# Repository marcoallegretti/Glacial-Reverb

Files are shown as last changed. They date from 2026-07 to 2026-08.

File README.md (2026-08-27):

# Koloured-Verb

A 12 HP Eurorack stereo reverb built on a Daisy Patch SM, using the
[eurorack-blocks](https://github.com/ohmtech-rdi/eurorack-blocks) framework.
Three boards: a carrier for the Daisy, a control board, and the panel.

Twelve reverb voices grouped into six families, ten post-reverb tail effects
grouped into five families, and a freeze pad with ducking.

## Rooms

Selected with the **ROOM** button. Short press cycles the family (RGB colour),
long press cycles the variant within it (RGB brightness dips = variant number).

| Family  | Colour  | Variants |
|---|---|---|
| Hall | blue | FDN tank · chamber |
| Plate | green | Dattorro · vintage · dispersive |
| Spring  | cyan | classic · long tank · dispersive  |
| Shimmer | yellow  | octave up · octave down (Abyss) |
| Cloud | magenta | granular over an FDN tank |
| Ambient | red | modulated Hadamard FDN |

Three variants per family is the ceiling: the LED renders a variant as a shade
of the family colour, and a fourth step is not readable against off.

The chamber runs a Moorer early-reflection tap bank and feeds the tank from the
taps rather than from the input, so each tap seeds the tank and the density
builds without the reflections reading as discrete echoes. The vintage plate
holds its high-frequency decay near a second whatever the decay knob does, as a
steel plate does. The long tank spreads its three spring delays while keeping
their chirp cutoffs together — the inverse of the short tank — and scatters at
the mid-point coupling ring. The dispersive voices use stretched-allpass chains
for the chirp.

## Tail effects

Selected with the **FX** button, same gesture (short = family, long = variant).
The red LED blinks the family number; None leaves the LED off. Each effect is
added over the untouched tail, so amount 0 is a true bypass.

| Family | Variants |
|---|---|
| None | — |
| Pitch | octave up · sub · chord (5th)  |
| Modulate | chorus · formant |
| Texture  | granular · reverse |
| Resonant | resonator · droplet |

## Panel

| Control | Function |
|---|---|
| FX pot | Morph: model character and tail-effect depth together |
| DECAY | Tail length |
| MIX | Wet added over the dry (additive, not a crossfade) |
| PRE DL | Pre-delay |
| DUCK | Input ducks the reverb |
| FRZ LV | Frozen pad level |
| FRZ MX | How much new signal enters the frozen pad |
| FRZ btn | Short press = freeze on/off · long press = tank-only on/off |
| ROOM btn  | Short = room family · long = variant |
| FX btn | Short = effect family · long = variant |
| FRZ G | Gate: forces freeze on |
| FX / FRZ LV / MIX / DECAY | CV over the corresponding pot |
| IN L/R | Audio in (R normalled to L) |
| OUT L/R | Audio out |

CV drives continuous character; the buttons handle discrete structure. Room and
effect selection step discretely rather than sweeping: a switch renders both
voices through a 150 ms crossfade and clears the outgoing one only once it is
silent, so the tail carries across a switch.

## Layout

```
eurorack/
  KoloredVerb.erbui          panel and control definition
  KoloredVerb.{h,cpp}        UI glue: selectors, gestures, LEDs
  KoloredVerbDsp.{h,cpp}     freeze pad, duck, mix, pre-delay wrapper
  dsp/                       reverb models, tail effects, shared DSP

hardware/
  core-board/                carrier: Daisy Patch SM, power, I/O expansion
  control-board/             pots, jacks, buttons, LEDs
  panel-board/               12 HP front panel
```

Each board folder holds its KiCad sources and a `fab/` directory with the
gerber zip and loose gerber set. See [hardware/README.md](hardware/README.md)
for the stack and what mates to what.

## Building

See [BUILD.md](BUILD.md) for the toolchain, firmware, simulator and board
fabrication. The `eurorack-blocks` framework is not vendored in this repository.

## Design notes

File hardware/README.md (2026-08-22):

# Koloured-Verb — hardware

Three boards, one 12 HP module.

```
  panel-board      12 HP FR4 panel: cutouts and baked labels
       │  pots / jacks / LEDs poke through
  control-board    panel parts on F.Cu, carrier headers on B.Cu
       │  ZZ1-5 / ZZ7 / ZZ12 + J6 / J9 / J11 plug down into…
  core-board       Daisy Patch SM host, power, I/O expansion
       │  4× 5×2 sockets host…
  Daisy Patch SM   Electrosmith submodule (bought, not fabricated)
```

| Folder | Board | Size | Assembly |
|---|---|---|---|
| [`core-board/`](core-board/) | carrier | 59.75 × 109.65 mm | 45 SMD by JLCPCB, 12 through-hole by hand |
| [`control-board/`](control-board/) | pots, jacks, buttons, LEDs | 59.75 × 109.65 mm | all by hand; one SMD RGB LED |
| [`panel-board/`](panel-board/) | 12 HP panel | 60.75 × 128.65 mm | none |

All three are 2-layer, 1.6 mm FR4. Each folder holds its KiCad sources, a
`<board>.bom.csv`, and `fab/` with the gerber zip and the loose set it was built
from. The core board also carries `fab/*-jlcpcb-bom.csv` and `-cpl.csv` for
assembly.

`ZZ10` on the control board is **DNP** — the core board carries no microSD, so
that header has no mating socket.

## Gerbers

```sh
kicad-cli pcb export gerbers --no-protel-ext \
  --layers F.Cu,B.Cu,F.Mask,B.Mask,F.Paste,B.Paste,F.Silkscreen,B.Silkscreen,Edge.Cuts \
  -o <board>/fab/gerber/ <board>/<name>.kicad_pcb
kicad-cli pcb export drill -o <board>/fab/gerber/ <board>/<name>.kicad_pcb
```

then zipped from `fab/gerber/`. The panel yields no paste layers — it carries no
SMD pads.

## Regenerating

The panel comes from `eurorack/KoloredVerb.erbui`; its labels are baked vector
outlines and cannot be edited in KiCad:

```sh
python3 hardware/panel-board/regen_panel.py
```

The control board cannot be regenerated — `erbb build hardware` parses it with a
KiCad-6-era reader that throws on KiCad 10 net syntax. Edit it in KiCad and treat
the committed board as the source of truth.

The core board's assembly files are derived from its own PCB:

```sh
"…/KiCad/10.0/bin/python.exe" hardware/core-board/derive_assembly.py
```

## Licensing

The control board and panel are generated from eurorack-blocks blocks, and the
core board derives from its kivu12. All carry **CC BY-SA 4.0** by derivation.
See [THIRD-PARTY.md](../THIRD-PARTY.md).

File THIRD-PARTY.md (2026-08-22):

# Third-party code and licences

KoloredVerb is not standalone work. What follows is what it stands on, who owns
it, and what that obliges us to do. Each entry was traced to a file in this
repository or in `deps/`, not assumed.

## Vendored into this repository

### `eurorack/dsp/ReverbSc.{h,cpp}` — MIT, © 2017 Raphael Dinge

Copied from `eurorack-blocks`, `samples/dsp/ReverbSc.{h,cpp}`. Verified identical
by its delay table (`{ 2473, 44, 14226, 1966 }`, upstream line 190).

This file is load-bearing: Hall wraps it, Shimmer and Abyss wrap it, Cloud runs
granular over it, and the freeze pad *is* it. Twelve of twelve rooms depend on it.

It is vendored rather than referenced so the DSP compiles standalone — against a
heap-backed `erb::SdramPtr` stub for the offline harness, and directly into the
MetaModule plugin, which has no eurorack-blocks at all.

The algorithm is Sean Costello's `reverbsc` (Stautner–Puckette FDN) as it appears
in Csound; the implementation here is Raphael Dinge's.

> **The copyright line above was missing.** Both files carried only
> `ReverbSc.cpp (local copy)` until it was restored. MIT's single obligation is
> that the notice travels with the copy, so that omission was a licence
> violation for as long as it stood. It is recorded here rather than quietly
> fixed.

## Built against, not vendored

### eurorack-blocks — MIT (software) / CC BY-SA 4.0 (hardware)

Per its README: *"All files in this repository, excluding `submodules/`, are
provided with the CC BY-SA 4.0 license for the hardware part, and MIT license for
the software part"*, with exceptions listed there (fonts under SIL OFL, etc.).

Both halves reach this project, and they are not the same licence:

- **Software (MIT)** — `erb::SdramPtr`, the `.erbui` code generators, the block
  library, the VCV Rack and Daisy build targets.
- **Hardware (CC BY-SA 4.0)** — the control board and panel are generated from
  eurorack-blocks blocks and the kivu12 board. **ShareAlike is copyleft**: the
  boards in `hardware/` carry BY-SA obligations regardless of
  the licence chosen for the software.

### kivu12 carrier board — part of eurorack-blocks (CC BY-SA 4.0, hardware)

**`hardware/core-board/` is an adaptation of the eurorack-blocks kivu12 rev7**,
by Raphael Dinge, used under CC BY-SA 4.0 and shared under the same licence.

Modified: parts this module does not use were removed (the second CD4051 and
CD4021 with their front ends, the CV-pitch conditioning block, the microSD block
and eleven LED resistors), CI1/CI2 were hard-wired to the ADC in place of the
jumpers, two freed Daisy inputs were tied to GND, and the eurorack-blocks logo
was removed from the silkscreen. The remaining routing is the original author's.

`hardware/core-board/reference-kivu12/` holds JLCPCB ordering files *derived*
from the framework's own fab set — rows removed, no values edited.

### Daisy Patch SM / libDaisy — Electrosmith

Reached as an eurorack-blocks submodule. `submodules/` are excluded from the
eurorack-blocks licence and carry their own.

## Status

- [x] ReverbSc copyright restored (`.cpp` and `.h`)
- [x] `LICENSE` — EUPL 1.2 for this project's own work
- [ ] MetaModule SDK terms — tracked on the `metamodule-port` branch, which is
      not part of this (master) history and must be settled before that branch
      is published. `metamodule/plugin.json` there still says
      `"license": "proprietary"`, a placeholder.

## On choosing a licence for our own work

MIT and CC BY-SA 4.0 upstream leave the software side open: MIT is permissive, so
MIT code may be carried into a copyleft work provided its notice travels with it —
which is what the restored header and this file are for.

The hardware is the constraint, not the software. CC BY-SA 4.0 attaches to the
boards by derivation, and a software licence does not displace it. Whatever is
chosen for the code, the boards stay ShareAlike.

This is a record of what the files say, not legal advice.

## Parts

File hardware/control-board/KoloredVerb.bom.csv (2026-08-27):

References | Description | MPN | Remarks | Quantity | Distributor | Distributor Part Number | Distributor Part URL
ZZ1 | CONN HEADER VERT 12POS 2.54MM | PBC12SAAN |  | 1 | Digikey | S1011E-12-ND | https://www.digikey.de/en/products/detail/sullins-connector-solutions/PBC12SAAN/859633
ZZ3, ZZ4, ZZ7, ZZ12 | CONN HEADER VERT 8POS 2.54MM | PBC08SAAN |  | 4 | Digikey | S1011E-08-ND | https://www.digikey.de/en/products/detail/sullins-connector-solutions/PBC08SAAN/859629
J11, J9 | CONN HEADER VERT 2POS 2.54MM | PBC02SAAN |  | 2 | Digikey | S1011E-02-ND | https://www.digikey.de/en/products/detail/sullins-connector-solutions/PBC02SAAN/859623
J6 | CONN HEADER VERT 4POS 2.54MM | PBC04SAAN |  | 1 | Digikey | S1011E-04-ND | https://www.digikey.de/en/products/detail/sullins-connector-solutions/PBC04SAAN/859625
ZZ10 | CONN HEADER VERT 6POS 2.54MM | PBC06SAAN | DNP - the core board has no microSD, so this header has no mating socket. Fitting it leaves 6 pins in the gap above the core board. | 0 | Digikey | S1011E-06-ND | https://www.digikey.de/en/products/detail/sullins-connector-solutions/PBC06SAAN/859627
ZZ2 | CONN HEADER VERT 9POS 2.54MM | PBC09SAAN |  | 1 | Digikey | S1011E-09-ND | https://www.digikey.de/en/products/detail/sullins-connector-solutions/PBC09SAAN/859630
ZZ5 | CONN HEADER VERT 10POS 2.54MM | PBC10SAAN |  | 1 | Digikey | PBC10SAAN | https://www.digikey.de/en/products/detail/sullins-connector-solutions/PBC10SAAN/859631
RV1, RV2, RV3, RV4, RV5, RV6, RV7 | ALPHA 9MM POTS – VERTICAL D-SHAFT | RD901F-40-15R1-B100K |  | 7 | Thonk | RD901F-B100K | https://www.thonk.co.uk/shop/alpha-9mm-pots-dshaft/
H3, H4, H5, H6, H7, H8, H9 | 1PS - Small Pointer (D Shaft) - Rogan PT Plastic Knob | Rogan 1PS |  | 7 | Thonk |  | https://www.thonk.co.uk/shop/make-noise-mutable-style-knobs/
J1, J10, J12, J2, J3, J4, J5, J7, J8 | Thonkiconn – 3.5mm Jack Sockets | PJ398SM |  | 9 | Thonk | PJ398SM | https://www.thonk.co.uk/shop/thonkiconn/
H10, H11, H12, H13, H14, H15, H16, H17, H18 | Knurled Nuts | PJ398SM nut | One nut bag contains already 50 pieces | 9 | Thonk |  | https://www.thonk.co.uk/shop/thonkiconn/
SW1, SW2, SW3 | C&K TACTILE SWITCH | D6R00 F1 LFS | Choose Black | 3 | Thonk |  | https://www.thonk.co.uk/shop/radio-music-switch/
D1, D3 | LED RED DIFFUSED T-1 T/H | WP710A10ID |  | 2 | Digikey | 754-1606-ND | https://www.digikey.com/en/products/detail/kingbright/WP710A10ID/2769809
D2 | LED RGB SMD PLCC4 - Cree CLV1A-FKB (common anode, FX indicator) | CLV1A-FKB-CJ1M1F1BB7R4S3 |  | 1 | Digikey | CLV1A-FKB-CJ1M1F1BB7R4S3 | https://www.cree.com/led-components/media/documents/CLV1AFKB(874).pdf

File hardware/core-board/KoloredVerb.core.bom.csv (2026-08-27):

References | Description | MPN | Quantity | Distributor | Distributor Part Number | LCSC Part Number
C1 C2 | CAP CER 10UF 25V X5R 0805 | CL21A106KAYNNNE | 2 | Digikey | 1276-2891-1-ND | C15850
C3 C5 C8 | CAP CER 0.1UF 25V X7R 0603 | CC0603KRX7R9BB104 | 3 | Digikey | 478-7018-1-ND | C14663
D1 D2 D3 D4 D5 D6 D7 D8 D30 | DIODE ARRAY SCHOTTKY 40V SOT323 | BAT54SW | 9 | Digikey | 497-14153-1-ND | C22466373
D23 D24 | DIODE SCHOTTKY 40V 1A SOD123 | B5819W SL | 2 | Digikey | 1N5819HW-FDICT-ND | C8598
Dummy1 Dummy2 Dummy3 Dummy4 | CONN HDR 10POS 0.1 GOLD PCB | PPPC052LFBN-RC | 4 | Digikey | S7108-ND
Dummy5 | CONN HEADER VERT 36POS 2.54MM | PBC36SAAN | 1 | Digikey | S1011E-36-ND
J0 | CONN HEADER VERT 10POS 2.54MM | 61201021621 | 1 | Digikey | 732-2094-ND
J1 | CONN HDR 12POS 0.1 TIN PCB | PPTC121LFBN-RC | 1 | Digikey | S6100-ND
J2 | CONN HDR 9POS 0.1 TIN PCB | PPTC091LFBN-RC | 1 | Digikey | S7007-ND
J3 J7 | CONN HDR 8POS 0.1 TIN PCB | PPTC081LFBN-RC | 2 | Digikey | S7006-ND
J4 | CONN HDR 8POS 0.1 TIN PCB | PPTC081LFBN-RC | 1 | Digikey | S7006-ND
J5 | CONN HDR 10POS 0.1 TIN PCB | PPTC101LFBN-RC | 1 | Digikey | S7008-ND
J6 | CONN HDR 4POS 0.1 TIN PCB | PPTC041LFBN-RC | 1 | Digikey | S7002-ND
J9 | CONN HDR 2POS 0.1 TIN PCB | PPTC021LFBN-RC | 1 | Digikey | S7000-ND
J11 | CONN HDR 2POS 0.1 TIN PCB | PPTC021LFBN-RC | 1 | Digikey | S7000-ND
J12 | CONN HDR 8POS 0.1 TIN PCB | PPTC081LFBN-RC | 1 | Digikey | S7006-ND
L1 L2 | FERRITE BEAD 1 KOHM 0603 1LN | BLM18AG102SN1D | 2 | Digikey | 732-1586-1-ND | C85824
R1 R47 R48 R49 R50 R51 | RES SMD 1K OHM 1% 1/10W 0603 | 0603WAF1001T5E | 6 | Digikey | 311-1KLDCT-ND | C21190
R4 R5 R6 R7 R8 R14 R15 R16 | RES SMD 100K OHM 1% 1/10W 0603 | 0603WAF1003T5E | 8 | Digikey | 541-100KHCT-ND | C25803
R79 R80 | RES SMD 4.7K OHM 1% 1/10W 0603 | 0603WAF4701T5E | 2 | Digikey | 311-4.70KHRCT-ND | C23162
R84 R85 R86 R87 R88 R89 R90 R91 | RES SMD 1M OHM 1% 1/10W 0603 | 0603WAF1004T5E | 8 | Digikey | 541-1.00MHCT-ND | C22935
U1 | IC MUX/DEMUX 8X1 16TSSOP | CD4051BPWR | 1 | Digikey | 296-11993-1-ND | C54587
U3 | IC STATIC SHFT REG 8STG 16-TSSOP | CD4021BPWR | 1 | Digikey | 296-14256-1-ND | C2877061
U6 | IC LED DRIVER RGBA 28-TSSOP | PCA9685PW | 1 | Digikey | 568-11925-1-ND | C2678753
DPSM1 | Audio submodule, plugs into the 4 sockets below | DAISY-PATCH-SM | 1 | Electrosmith | DAISY-PATCH-SM

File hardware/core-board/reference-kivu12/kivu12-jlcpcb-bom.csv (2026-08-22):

Comment | Designator | Footprint | LCSC Part #
100k | R4,R5,R6,R7,R8,R14,R15,R16,R17,R18,R24,R25,R26,R27,R28,R34,R68,R69,R72,R73,R81,R82 | Resistor_SMD:R_0603_1608Metric | C25803
1K | R1,R2,R44,R45,R46,R47,R48,R49,R50,R51,R52,R53,R54,R55,R56,R57,R58,R59 | Resistor_SMD:R_0603_1608Metric | C21190
1M | R84,R85,R86,R87,R88,R89,R90,R91,R92,R93,R94,R95,R96,R97,R98,R99 | Resistor_SMD:R_0603_1608Metric | C22935
4.7k | R79,R80 | Resistor_SMD:R_0603_1608Metric | C23162
4.99k | R76 | Resistor_SMD:R_0603_1608Metric | C23046
100n | C3,C4,C5,C6,C8,C11,C12 | Capacitor_SMD:C_0603_1608Metric | C14663
1u | C13 | Capacitor_SMD:C_0603_1608Metric | C15849
10u | C1,C2 | Capacitor_SMD:C_0805_2012Metric | C15850
BAT54SW | D1,D2,D3,D4,D5,D6,D7,D8,D9,D10,D11,D12,D13,D14,D15,D16,D30 | Package_TO_SOT_SMD:SOT-323_SC-70 | C22466373
D_Schottky | D23,D24 | Diode_SMD:D_SOD-123 | C8598
Ferrite_Bead | L1,L2 | Inductor_SMD:L_0603_1608Metric | C85824
4051 | U1,U2 | Package_SO:TSSOP-16_4.4x5mm_P0.65mm | C54587
4021 | U3,U4 | Package_SO:TSSOP-16_4.4x5mm_P0.65mm | C2877061
LM4040DBZ-5 | D22 | Package_TO_SOT_SMD:SOT-23 | C156291
PCA9685PW | U6 | Package_SO:TSSOP-28_4.4x9.7mm_P0.65mm | C2678753
TL072 | U9 | Package_SO:SOIC-8_3.9x4.9mm_P1.27mm | C67473

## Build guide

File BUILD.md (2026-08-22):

# Building and fabricating Koloured-Verb

## Toolchain

- [eurorack-blocks](https://github.com/ohmtech-rdi/eurorack-blocks) — not vendored
  here. Clone it and initialise its submodules (`gyp-next` is required to generate
  the build; `vcv-rack-sdk` for the simulator):

  ```sh
  git submodule update --init submodules/gyp-next submodules/vcv-rack-sdk
  ```

  Point the project at it via `dep/eurorack-blocks` (a link or junction).
- Python 3.12 (the framework's bundled `python3-packages` are built for cp312).
- MinGW-w64 g++ (MSYS2 `mingw64`) on Windows.
- KiCad 10 for the boards and `kicad-cli` gerber export. The framework's panel
  generators separately shell out to a **bundled KiCad 6**, which lives under
  `build-system/toolchain/` and is not part of the source tree.

### Local layout on this machine

The framework is kept in `deps/eurorack-blocks/` so builds do not reach into
whichever scattered clone happens to be on `PATH`. Three links make that work —
all inside gitignored `dep/`/`deps/`, so none of this is committed:

| Link | Target | Why |
|---|---|---|
| `dep/eurorack-blocks` | `deps/eurorack-blocks` | what the build system looks for |
| `deps/eurorack-blocks/submodules/gyp-next` | a populated clone | needed to *generate* the build |
| `deps/eurorack-blocks/submodules/vcv-rack-sdk` | a populated SDK | `libRack` for the simulator |
| `deps/eurorack-blocks/build-system/toolchain` | the bundled toolchain | KiCad 6 + cairo DLLs for the panel generators |

Invoke the **vendored** `erbb`, not whichever one is on `PATH`:

```sh
deps/eurorack-blocks/build-system/scripts/erbb
```

This matters: the generated `KoloredVerbUi.h` bakes in the path to
`BoardKivu12.h`, so an `erbb` from a different clone silently compiles the
firmware against that clone's framework instead of the vendored one.

## Firmware (Daisy)

```sh
erbb configure
erbb build daisy --configuration release
```

## Simulator (VCV Rack)

```sh
erbb configure
erbb build simulator --configuration debug
```

Headless on Windows, MSYS `make` drops the MinGW `PATH` when spawning `g++`, so
the compile step fails even though the source generation succeeded. Run make
directly from a shell that has the environment set:

```sh
export PATH="/c/msys64/mingw64/bin:$PATH"
export HOME=/c/Users/<you>; export MSYSTEM=MINGW64
cd eurorack/artifacts/simulator && make -j1 install
```

The plugin installs to `%LOCALAPPDATA%/Rack2/plugins-win-x64/KoloredVerb/`.
This target never touches the hardware files.

### The generated manifest carries the wrong identity

`erbui/generators/vcvrack/manifest.py` writes `plugin.json` with the framework's
identity hardcoded — slug `ErbPluginKoloredVerb`, brand and author `Erb`, every
URL pointing at ohmtech-rdi, and `"license": "proprietary"` — and it rewrites the
file on **every** build, so the correction cannot be committed into the artifact.
Stamp it afterwards:

```sh
python3 ci/vcv_manifest.py $(find eurorack/artifacts -name plugin.json)
```

That sets the 23DSP identity and the EUPL-1.2 licence, and leaves the module slug
alone — it has to keep matching the string `plugin_vcvrack.cpp` passes to
`rack::createModel`. The release workflow runs this step automatically and also
stamps the tag as the version.

## Hardware fabrication

Deliverables live under `hardware/`, one folder per board:

| Board | Gerbers | BOM |
|---|---|---|
| Core | `core-board/fab/KoloredVerb.core.gerber.zip` | `core-board/KoloredVerb.core.bom.csv` |
| Control | `control-board/fab/KoloredVerb.gerber.zip` | `control-board/KoloredVerb.bom.csv` |
| Panel | `panel-board/fab/KoloredVerb.panel.gerber.zip` | none — mechanical |

All 2-layer, 1.6 mm FR4; the panel is fabricated as a PCB like the boards.

The core board's 45 SMD parts are assembled by JLCPCB from
`core-board/fab/KoloredVerb.core-jlcpcb-bom.csv` and `-cpl.csv`; its 12
through-hole parts and the whole control board are hand-soldered. `ZZ10` on the
control board is DNP — the core board has no microSD, so it has no mating socket.

### Regenerating the panel

The panel is FR4 (`material pcb` in the `.erbui`), so it is fabricated from
gerbers like the other two boards — no DXF or PDF is emitted, and none is
needed. Labels are baked to vector outlines and cannot be edited in KiCad, so
any label or control change has to come back through the `.erbui`:

```sh
python3 hardware/panel-board/regen_panel.py
```

Use a Python **3.12** interpreter — the framework's bundled `python3-packages`
(cffi, cairo) are cp312 builds.

The script calls only the four `generate_front_panel_*` steps, then re-exports
the gerbers with `kicad-cli`. It deliberately does **not** call
`erbb build hardware`, which would run `generate_front_pcb_kicad_pcb` against
the frozen control board. As a backstop it sha256s the control board before and
after and fails loudly if it moved.

Regeneration is faithful but not byte-stable: KiCad footprint UUIDs and the
footprint ordering are regenerated each run, so the `.kicad_pcb` churns while
the board does not. Verify by exported geometry, not by file hash — after the
rename regeneration the vertex set of every gerber layer was unchanged.

### Control board: do not regenerate

`erbb build hardware` cannot regenerate `KoloredVerb.kicad_pcb`. The framework
reads the existing board with a KiCad 6 era parser, which throws on KiCad 10 net
syntax. Placement is owned by the `.erbui`, but apply control-board changes directly
in KiCad and keep the committed board as the source of truth. Only the panel
generators above are safe to re-run; hash the control board before and after any
build to confirm it is untouched.

## Verifying the DSP

The DSP is host-independent and can be exercised without hardware or Rack:
compile `KoloredVerbDsp.cpp` against a heap-backed `erb::SdramPtr` stub and
drive it with impulses and noise, measuring RT60, L/R correlation, peak, NaN and
stability across every model x effect combination.

Build with `-D_GLIBCXX_ASSERTIONS` so `std::array::operator[]` traps
out-of-range indices, and use the simulator's real sample rate (48014, not
48000). Delay-line index bugs can need seconds of runtime to surface, so soak
each combination rather than sampling it briefly.

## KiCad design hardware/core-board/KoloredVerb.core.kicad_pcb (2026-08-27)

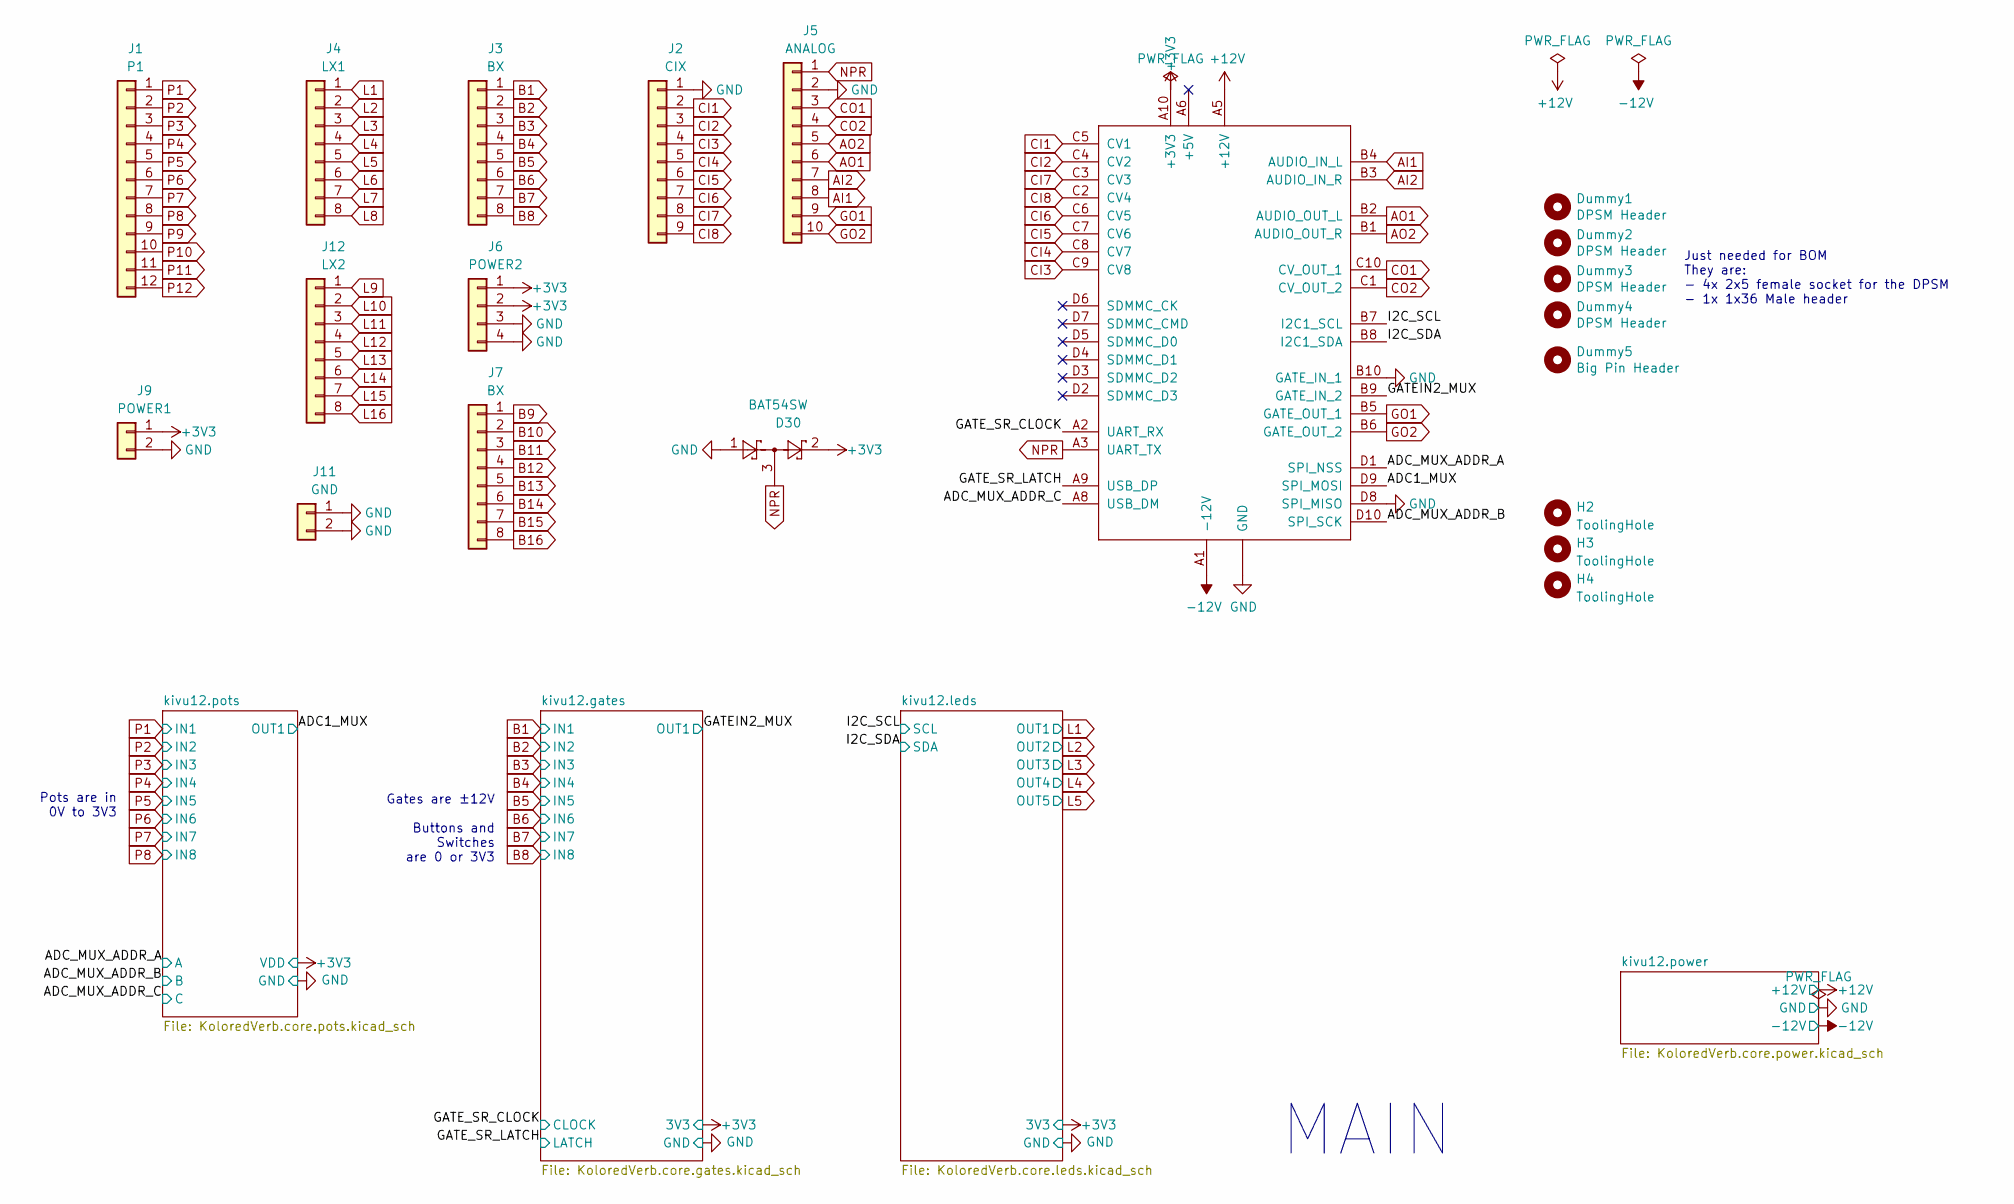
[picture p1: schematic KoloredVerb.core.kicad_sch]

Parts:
D30: BAT54SW; SOT-323_SC-70; MPN BAT54SW; JlcPcbPartNumber C22466373
DPSM1: DaisyPatchSm_Rev1; DaisyPatchSm; MPN DAISY-PATCH-SM
Dummy1, Dummy2, Dummy3, Dummy4: DPSM Header; Empty; MPN PPPC052LFBN-RC
Dummy5: Big Pin Header; Empty; MPN PBC36SAAN
H2, H3, H4: ToolingHole; JlcPcbToolingHole
J1: P1; PinSocket_1x12_P2.54mm_Vertical; MPN PPTC121LFBN-RC
J2: CIX; PinSocket_1x09_P2.54mm_Vertical; MPN PPTC091LFBN-RC
J3, J7: BX; PinSocket_1x08_P2.54mm_Vertical; MPN PPTC081LFBN-RC
J4: LX1; PinSocket_1x08_P2.54mm_Vertical; MPN PPTC081LFBN-RC
J5: ANALOG; PinSocket_1x10_P2.54mm_Vertical; MPN PPTC101LFBN-RC
J6: POWER2; PinSocket_1x04_P2.54mm_Vertical; MPN PPTC041LFBN-RC
J9: POWER1; PinSocket_1x02_P2.54mm_Vertical; MPN PPTC021LFBN-RC
J11: GND; PinSocket_1x02_P2.54mm_Vertical; MPN PPTC021LFBN-RC
J12: LX2; PinSocket_1x08_P2.54mm_Vertical; MPN PPTC081LFBN-RC

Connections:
+3V3: D30.2, DPSM1.A10 (+3V3), J6.1, J6.2, J9.1; also elsewhere on the board
+12V: DPSM1.A5 (+12V); also elsewhere on the board
-12V: DPSM1.A1 (-12V); also elsewhere on the board
/ADC1_MUX: DPSM1.D9 (SPI_MOSI); also elsewhere on the board
/ADC_MUX_ADDR_A: DPSM1.D1 (SPI_NSS); also elsewhere on the board
/ADC_MUX_ADDR_B: DPSM1.D10 (SPI_SCK); also elsewhere on the board
/ADC_MUX_ADDR_C: DPSM1.A8 (USB_DM); also elsewhere on the board
/GATEIN2_MUX: DPSM1.B9 (GATE_IN_2); also elsewhere on the board
/GATE_SR_CLOCK: DPSM1.A2 (UART_RX); also elsewhere on the board
/GATE_SR_LATCH: DPSM1.A9 (USB_DP); also elsewhere on the board
/I2C_SCL: DPSM1.B7 (I2C1_SCL); also elsewhere on the board
/I2C_SDA: DPSM1.B8 (I2C1_SDA); also elsewhere on the board
AI1: DPSM1.B4 (AUDIO_IN_L), J5.8
AI2: DPSM1.B3 (AUDIO_IN_R), J5.7
AO1: DPSM1.B2 (AUDIO_OUT_L), J5.6
AO2: DPSM1.B1 (AUDIO_OUT_R), J5.5
B1: J3.1; also elsewhere on the board
B2: J3.2; also elsewhere on the board
B3: J3.3; also elsewhere on the board
B4: J3.4; also elsewhere on the board
B5: J3.5; also elsewhere on the board
B6: J3.6; also elsewhere on the board
B7: J3.7; also elsewhere on the board
B8: J3.8; also elsewhere on the board
B9: J7.1
B10: J7.2
B11: J7.3
B12: J7.4
B13: J7.5
B14: J7.6
B15: J7.7
B16: J7.8
CI1: DPSM1.C5 (CV1), J2.2
CI2: DPSM1.C4 (CV2), J2.3
CI3: DPSM1.C9 (CV8), J2.4
CI4: DPSM1.C8 (CV7), J2.5
CI5: DPSM1.C7 (CV6), J2.6
CI6: DPSM1.C6 (CV5), J2.7
CI7: DPSM1.C3 (CV3), J2.8
CI8: DPSM1.C2 (CV4), J2.9
CO1: DPSM1.C10 (CV_OUT_1), J5.3
CO2: DPSM1.C1 (CV_OUT_2), J5.4
GND: D30.1, DPSM1.A4 (GND), DPSM1.A7 (GND), DPSM1.B10 (GATE_IN_1), DPSM1.D8 (SPI_MISO), J2.1, J5.2, J6.3, J6.4, J9.2, J11.1, J11.2; also elsewhere on the board
GO1: DPSM1.B5 (GATE_OUT_1), J5.9
GO2: DPSM1.B6 (GATE_OUT_2), J5.10
L1: J4.1; also elsewhere on the board
L2: J4.2; also elsewhere on the board
L3: J4.3; also elsewhere on the board
L4: J4.4; also elsewhere on the board
L5: J4.5; also elsewhere on the board
L6: J4.6
L7: J4.7
L8: J4.8
L9: J12.1
L10: J12.2
L11: J12.3
L12: J12.4
L13: J12.5
L14: J12.6
L15: J12.7
L16: J12.8
NPR: D30.3, DPSM1.A3 (UART_TX), J5.1
P1: J1.1; also elsewhere on the board
P2: J1.2; also elsewhere on the board
P3: J1.3; also elsewhere on the board
P4: J1.4; also elsewhere on the board
P5: J1.5; also elsewhere on the board
P6: J1.6; also elsewhere on the board
P7: J1.7; also elsewhere on the board
P8: J1.8; also elsewhere on the board
P9: J1.9
P10: J1.10
P11: J1.11
P12: J1.12

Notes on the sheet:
Just needed for BOM They are: - 4x 2x5 female socket for the DPSM - 1x 1x36 Male header
Pots are in 0V to 3V3
Gates are ±12V Buttons and Switches are 0 or 3V3
MAIN

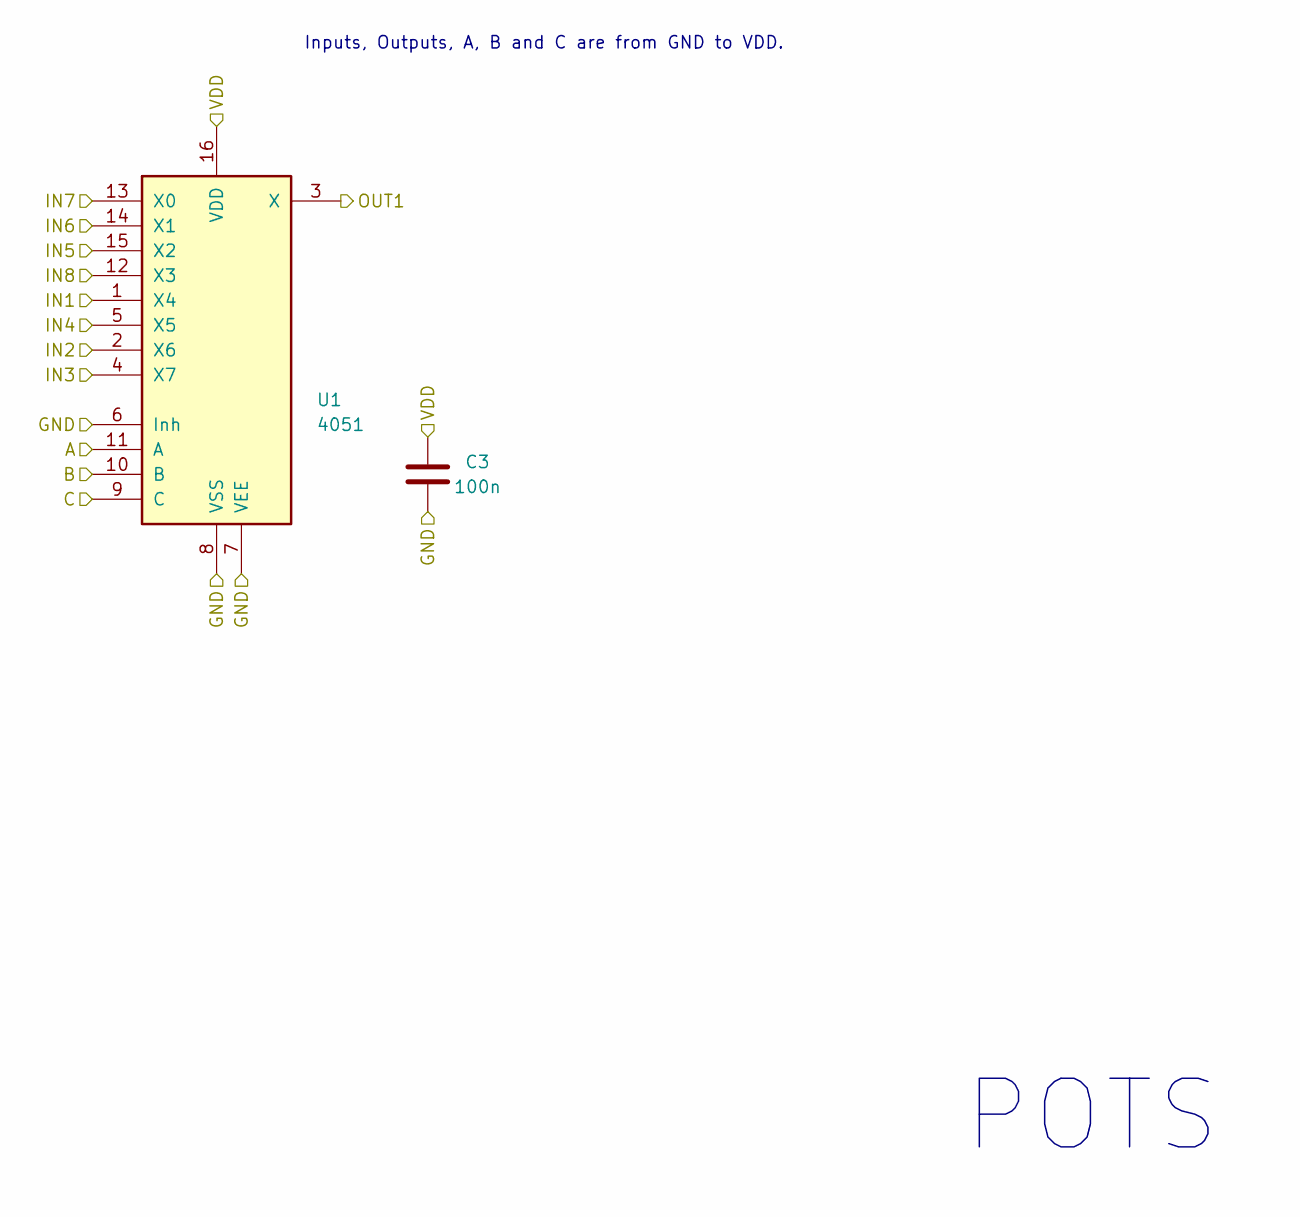
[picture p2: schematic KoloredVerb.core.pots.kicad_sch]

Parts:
C3: 100n; C_0603_1608Metric; MPN CC0603KRX7R9BB104; JlcPcbPartNumber C14663
U1: 4051; TSSOP-16_4.4x5mm_P0.65mm; MPN CD4051BPWR; JlcPcbPartNumber C54587

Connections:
+3V3: C3.2, U1.16 (VDD); also elsewhere on the board
/ADC1_MUX: U1.3 (X); also elsewhere on the board
/ADC_MUX_ADDR_A: U1.11 (A); also elsewhere on the board
/ADC_MUX_ADDR_B: U1.10 (B); also elsewhere on the board
/ADC_MUX_ADDR_C: U1.9 (C); also elsewhere on the board
GND: C3.1, U1.6 (Inh), U1.7 (VEE), U1.8 (VSS); also elsewhere on the board
P1: U1.1 (X4); also elsewhere on the board
P2: U1.2 (X6); also elsewhere on the board
P3: U1.4 (X7); also elsewhere on the board
P4: U1.5 (X5); also elsewhere on the board
P5: U1.15 (X2); also elsewhere on the board
P6: U1.14 (X1); also elsewhere on the board
P7: U1.13 (X0); also elsewhere on the board
P8: U1.12 (X3); also elsewhere on the board

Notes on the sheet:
Inputs, Outputs, A, B and C are from GND to VDD.
POTS

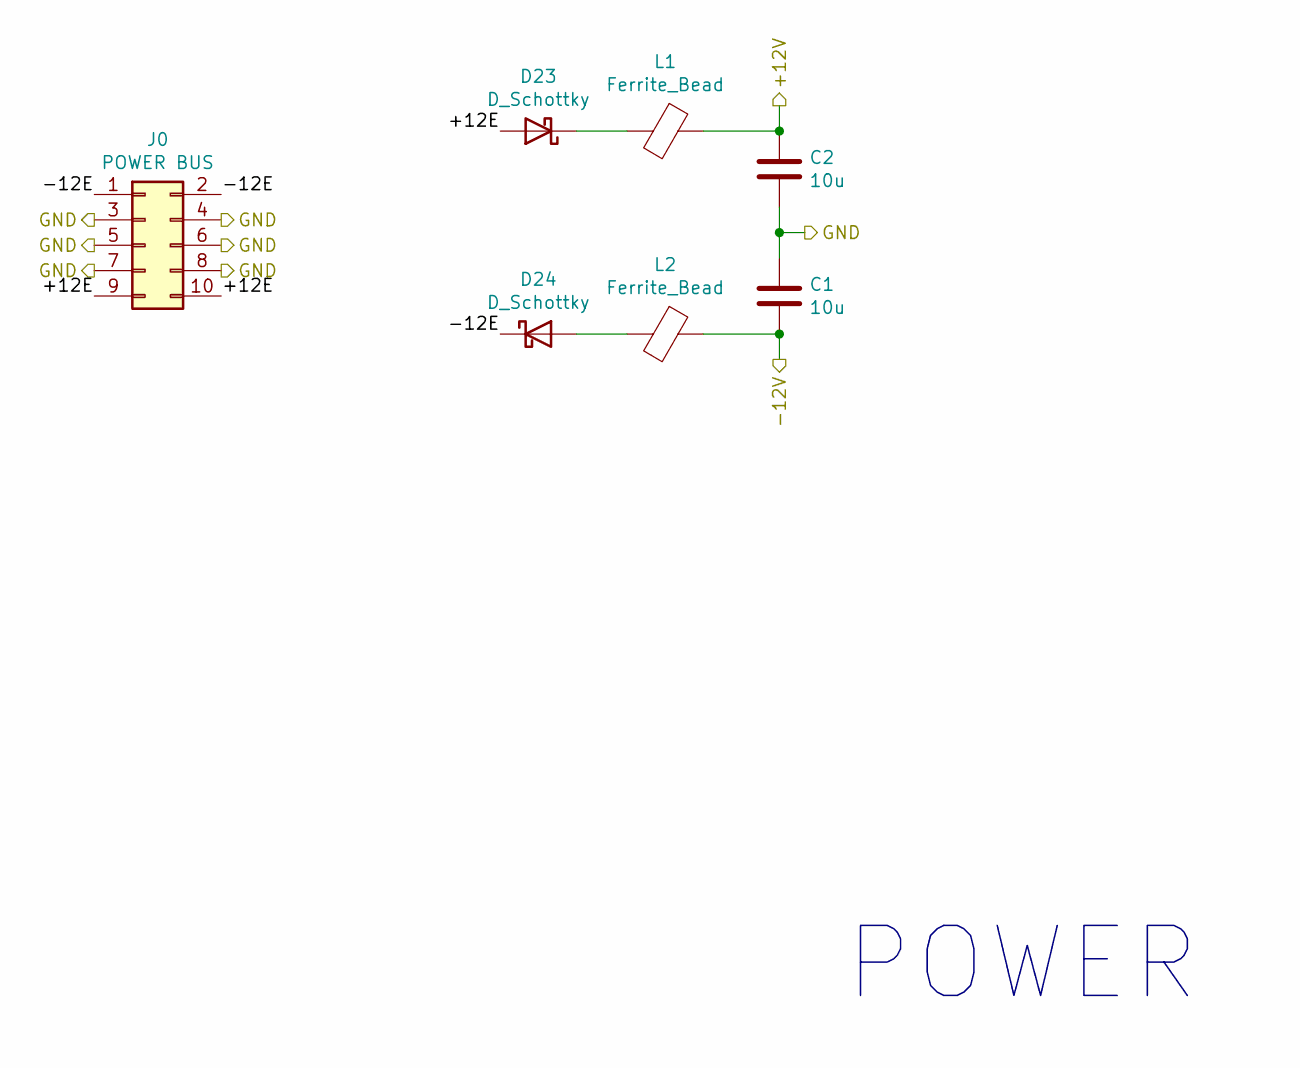
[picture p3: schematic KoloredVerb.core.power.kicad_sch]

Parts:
C1, C2: 10u; C_0805_2012Metric; MPN CL21A106KAYNNNE; JlcPcbPartNumber C15850
D23, D24: D_Schottky; D_SOD-123; MPN B5819W SL; JlcPcbPartNumber C8598
J0: POWER BUS; IDC-Header_2x05_P2.54mm_Vertical; MPN 61201021621
L1, L2: Ferrite_Bead; L_0603_1608Metric; MPN BLM18AG102SN1D; JlcPcbPartNumber C85824

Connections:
+12V: C2.1, L1.1; also elsewhere on the board
-12V: C1.2, L2.1; also elsewhere on the board
/kivu12.power/+12E: D23.2 (A), J0.9, J0.10
/kivu12.power/-12E: D24.1 (K), J0.1, J0.2
GND: C1.1, C2.2, J0.3, J0.4, J0.5, J0.6, J0.7, J0.8; also elsewhere on the board
unnamed: D23.1 (K), L1.2
unnamed: D24.2 (A), L2.2

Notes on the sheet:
POWER

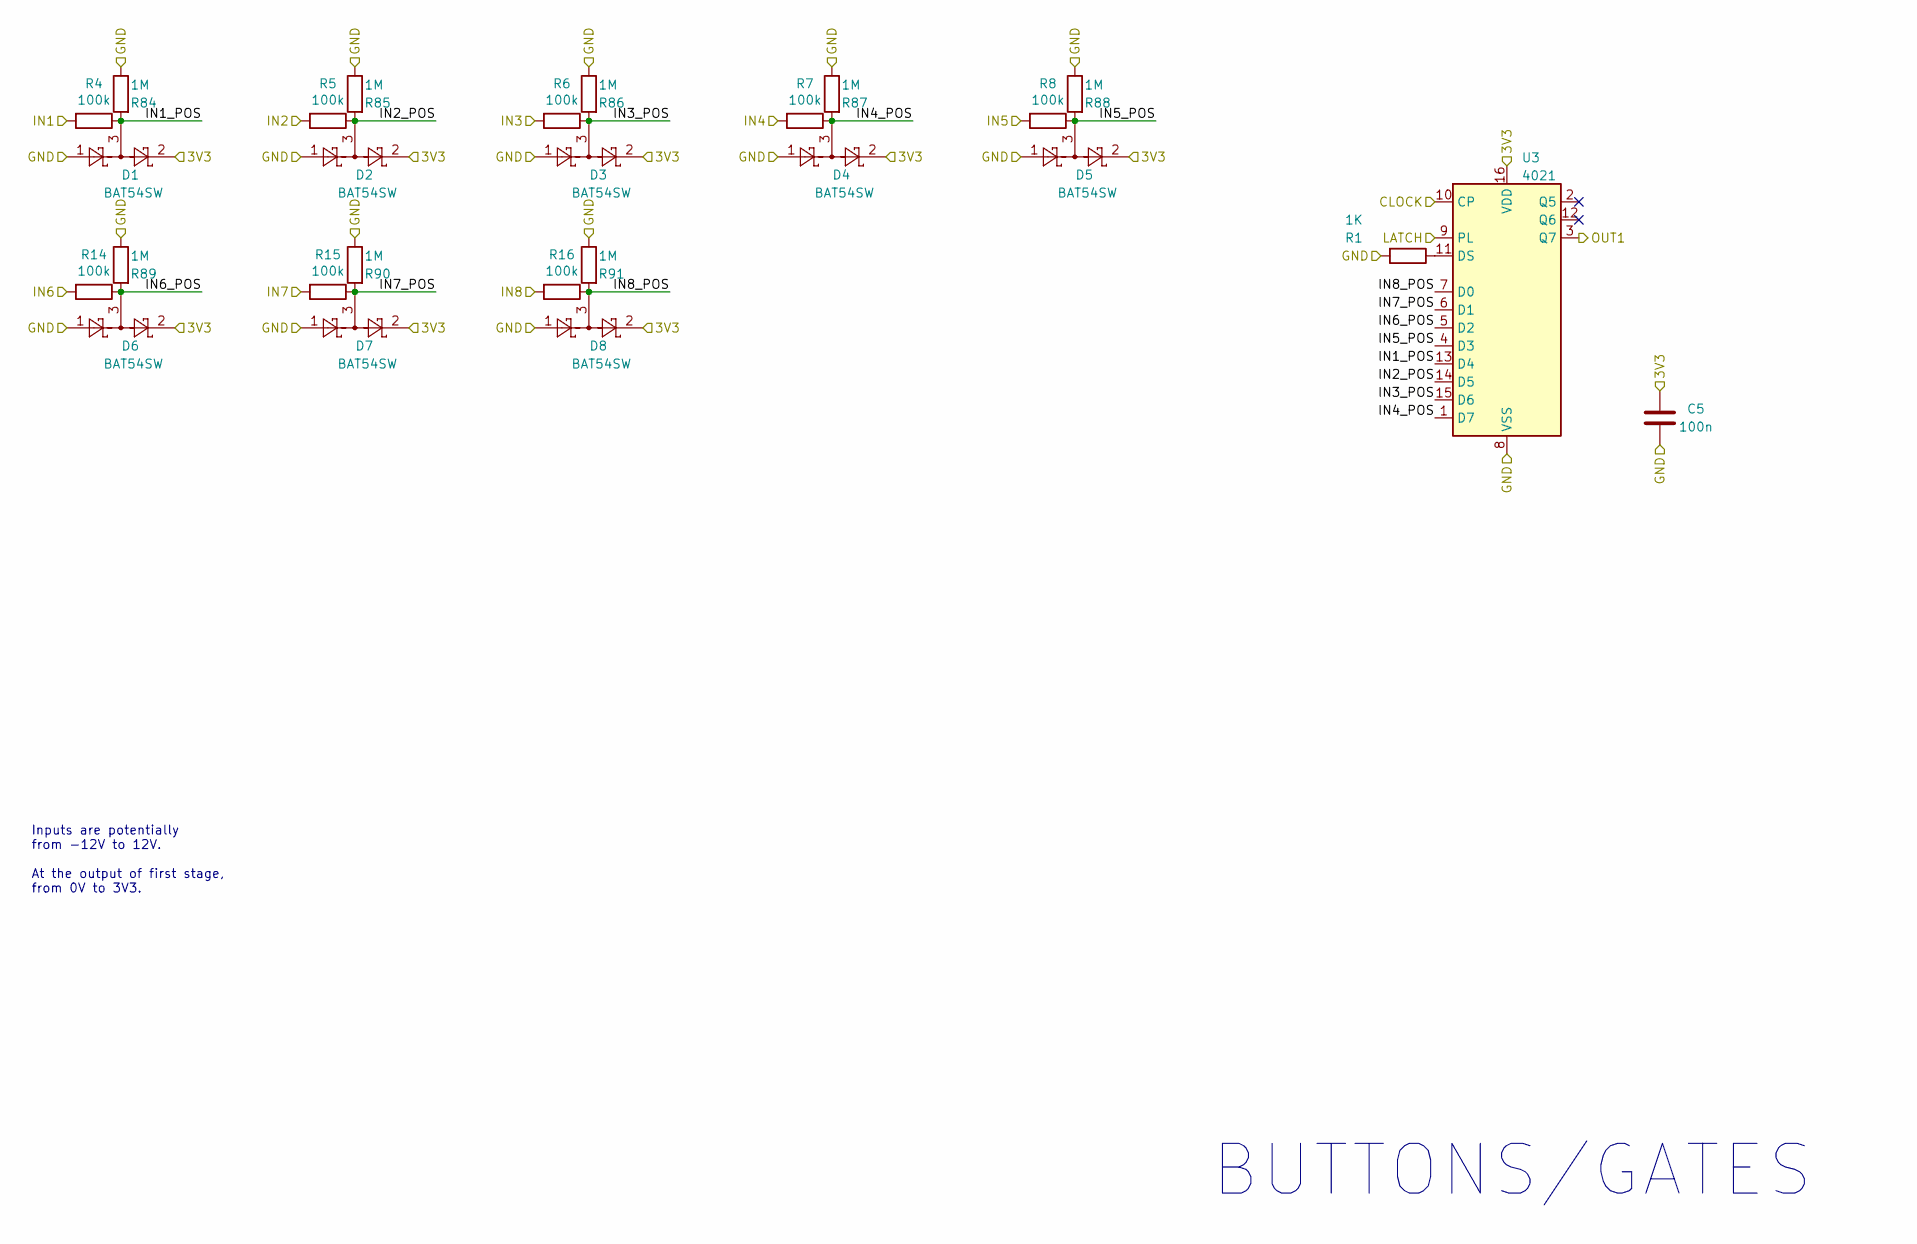
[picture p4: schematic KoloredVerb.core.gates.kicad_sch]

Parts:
C5: 100n; C_0603_1608Metric; MPN CC0603KRX7R9BB104; JlcPcbPartNumber C14663
D1, D2, D3, D4, D5, D6, D7, D8: BAT54SW; SOT-323_SC-70; MPN BAT54SW; JlcPcbPartNumber C22466373
R1: 1K; R_0603_1608Metric; MPN 0603WAF1001T5E; JlcPcbPartNumber C21190
R4, R5, R6, R7, R8, R14, R15, R16: 100k; R_0603_1608Metric; MPN 0603WAF1003T5E; JlcPcbPartNumber C25803
R84, R85, R86, R87, R88, R89, R90, R91: 1M; R_0603_1608Metric; MPN 0603WAF1004T5E; JlcPcbPartNumber C22935
U3: 4021; TSSOP-16_4.4x5mm_P0.65mm; MPN CD4021BPWR; JlcPcbPartNumber C2877061

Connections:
+3V3: C5.2, D1.2, D2.2, D3.2, D4.2, D5.2, D6.2, D7.2, D8.2, U3.16 (VDD); also elsewhere on the board
/GATEIN2_MUX: U3.3 (Q7); also elsewhere on the board
/GATE_SR_CLOCK: U3.10 (CP); also elsewhere on the board
/GATE_SR_LATCH: U3.9 (PL); also elsewhere on the board
/kivu12.gates/IN1_POS: D1.3, R4.1, R84.2, U3.13 (D4)
/kivu12.gates/IN2_POS: D2.3, R5.1, R85.2, U3.14 (D5)
/kivu12.gates/IN3_POS: D3.3, R6.1, R86.2, U3.15 (D6)
/kivu12.gates/IN4_POS: D4.3, R7.1, R87.2, U3.1 (D7)
/kivu12.gates/IN5_POS: D5.3, R8.1, R88.2, U3.4 (D3)
/kivu12.gates/IN6_POS: D6.3, R14.1, R89.2, U3.5 (D2)
/kivu12.gates/IN7_POS: D7.3, R15.1, R90.2, U3.6 (D1)
/kivu12.gates/IN8_POS: D8.3, R16.1, R91.2, U3.7 (D0)
B1: R4.2; also elsewhere on the board
B2: R5.2; also elsewhere on the board
B3: R6.2; also elsewhere on the board
B4: R7.2; also elsewhere on the board
B5: R8.2; also elsewhere on the board
B6: R14.2; also elsewhere on the board
B7: R15.2; also elsewhere on the board
B8: R16.2; also elsewhere on the board
GND: C5.1, D1.1, D2.1, D3.1, D4.1, D5.1, D6.1, D7.1, D8.1, R1.2, R84.1, R85.1, R86.1, R87.1, R88.1, R89.1, R90.1, R91.1, U3.8 (VSS); also elsewhere on the board
unnamed: R1.1, U3.11 (DS)

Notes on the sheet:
BUTTONS/GATES
Inputs are potentially from -12V to 12V. At the output of first stage, from 0V to 3V3.

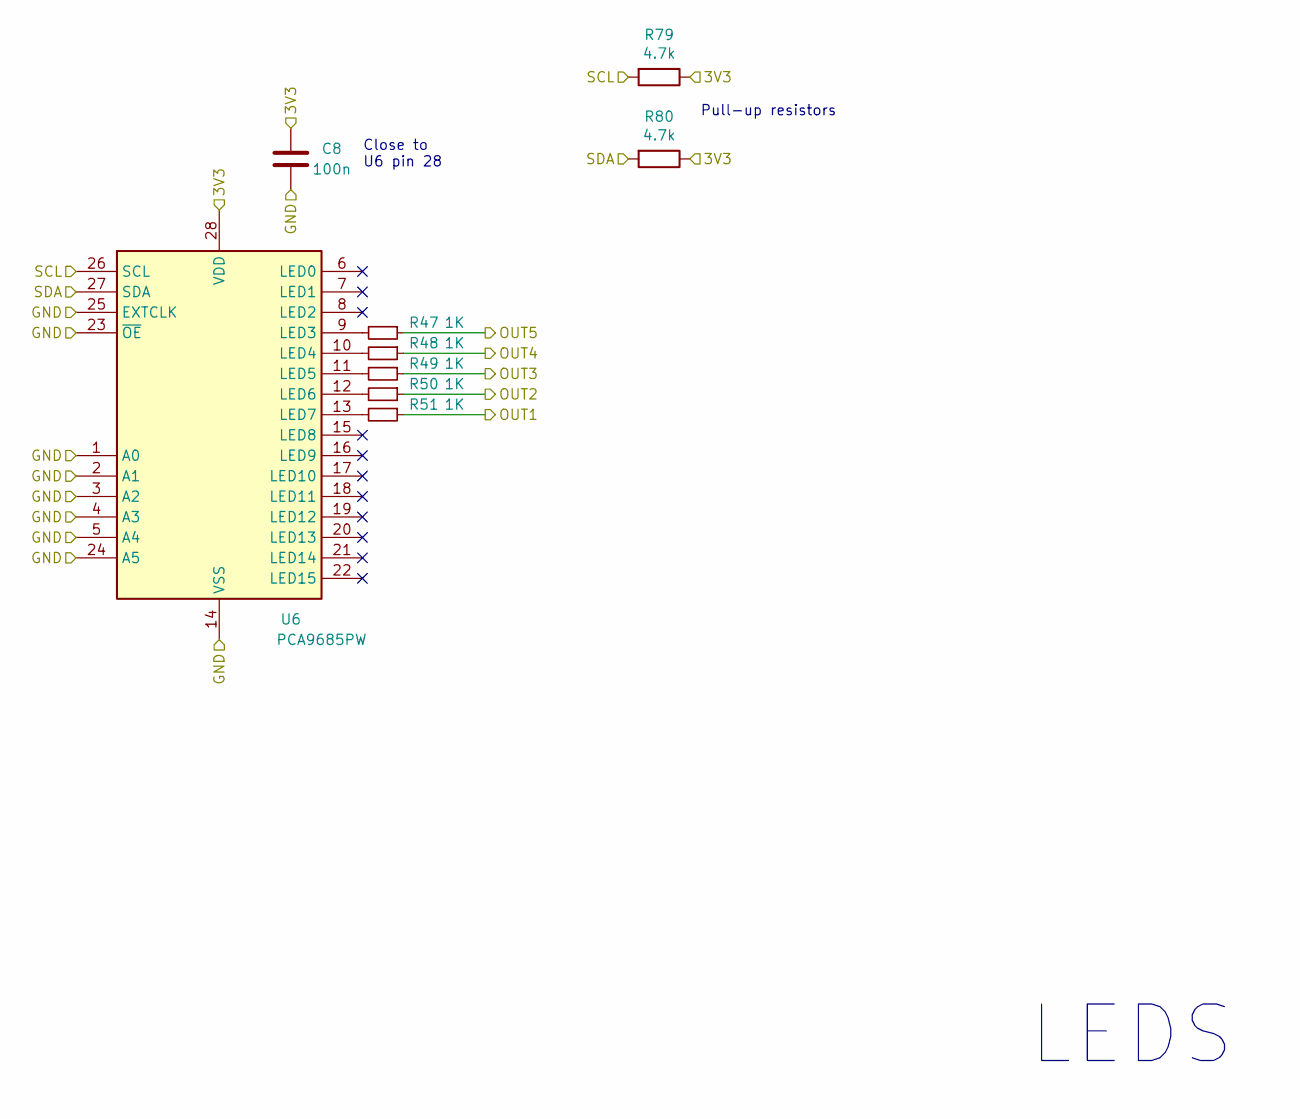
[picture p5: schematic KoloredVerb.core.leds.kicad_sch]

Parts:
C8: 100n; C_0603_1608Metric; MPN CC0603KRX7R9BB104; JlcPcbPartNumber C14663
R47, R48, R49, R50, R51: 1K; R_0603_1608Metric; MPN 0603WAF1001T5E; JlcPcbPartNumber C21190
R79, R80: 4.7k; R_0603_1608Metric; MPN 0603WAF4701T5E; JlcPcbPartNumber C23162
U6: PCA9685PW; TSSOP-28_4.4x9.7mm_P0.65mm; MPN PCA9685PW; JlcPcbPartNumber C2678753

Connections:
+3V3: C8.2, R79.1, R80.1, U6.28 (VDD); also elsewhere on the board
/I2C_SCL: R79.2, U6.26 (SCL); also elsewhere on the board
/I2C_SDA: R80.2, U6.27 (SDA); also elsewhere on the board
GND: C8.1, U6.1 (A0), U6.2 (A1), U6.3 (A2), U6.4 (A3), U6.5 (A4), U6.14 (VSS), U6.23 (~OE), U6.24 (A5), U6.25 (EXTCLK); also elsewhere on the board
L1: R51.1; also elsewhere on the board
L2: R50.1; also elsewhere on the board
L3: R49.1; also elsewhere on the board
L4: R48.1; also elsewhere on the board
L5: R47.1; also elsewhere on the board
unnamed: R47.2, U6.9 (LED3)
unnamed: R48.2, U6.10 (LED4)
unnamed: R49.2, U6.11 (LED5)
unnamed: R50.2, U6.12 (LED6)
unnamed: R51.2, U6.13 (LED7)

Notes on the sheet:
Close to U6 pin 28
Pull-up resistors
LEDS

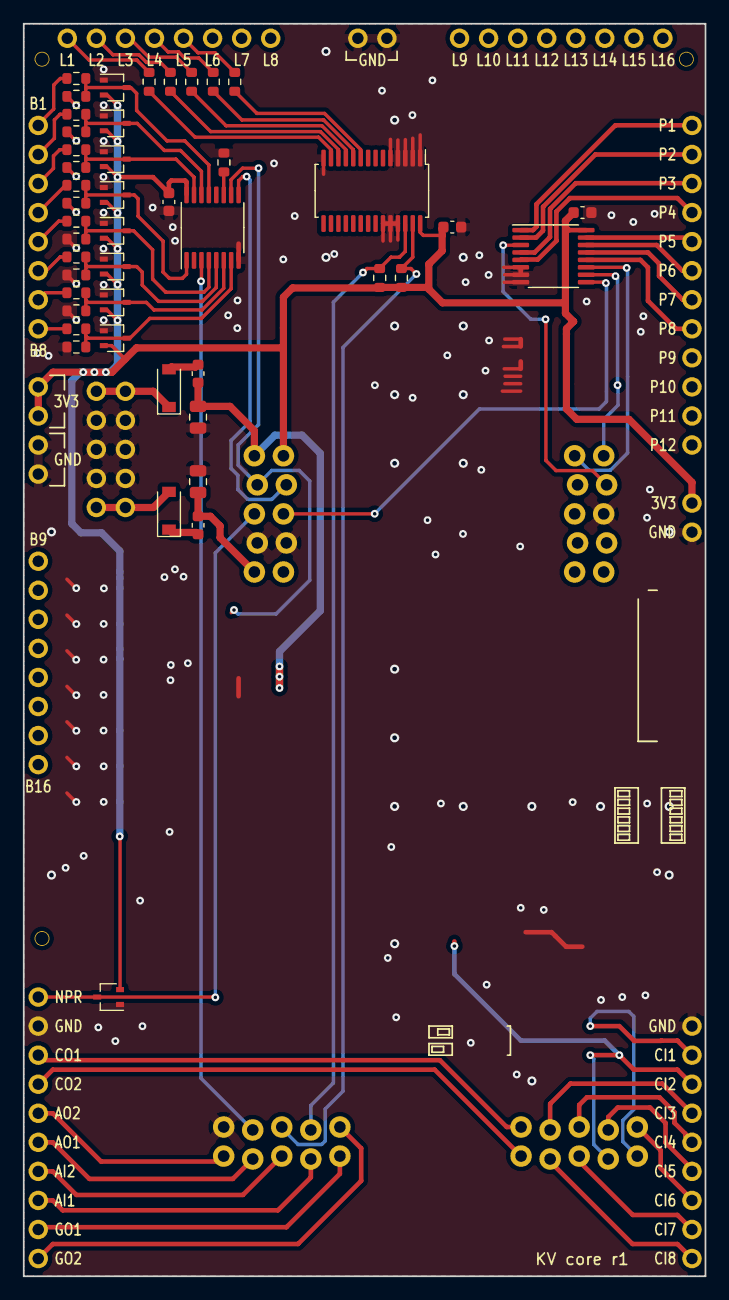
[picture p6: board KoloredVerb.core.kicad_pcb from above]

Board: 2 copper layers, 59.6 x 109.5 mm, 65 parts (1 on the bottom side), 69 nets.

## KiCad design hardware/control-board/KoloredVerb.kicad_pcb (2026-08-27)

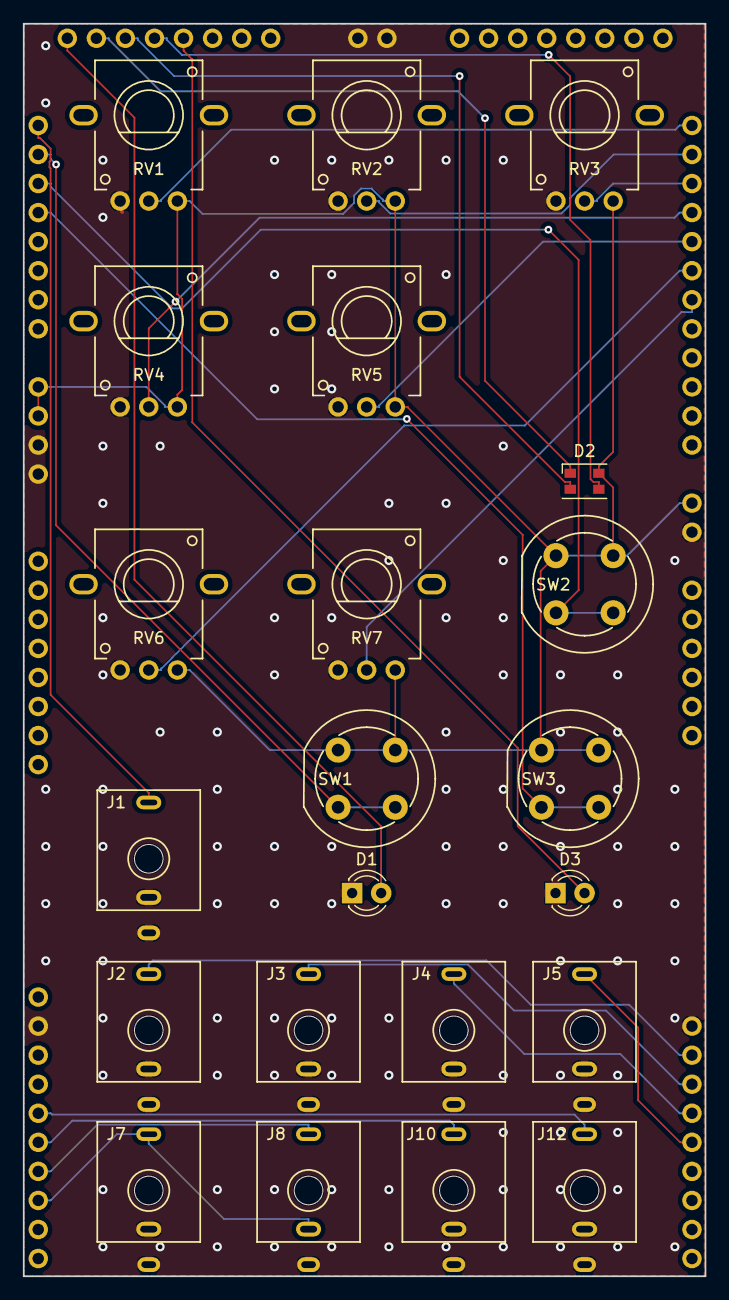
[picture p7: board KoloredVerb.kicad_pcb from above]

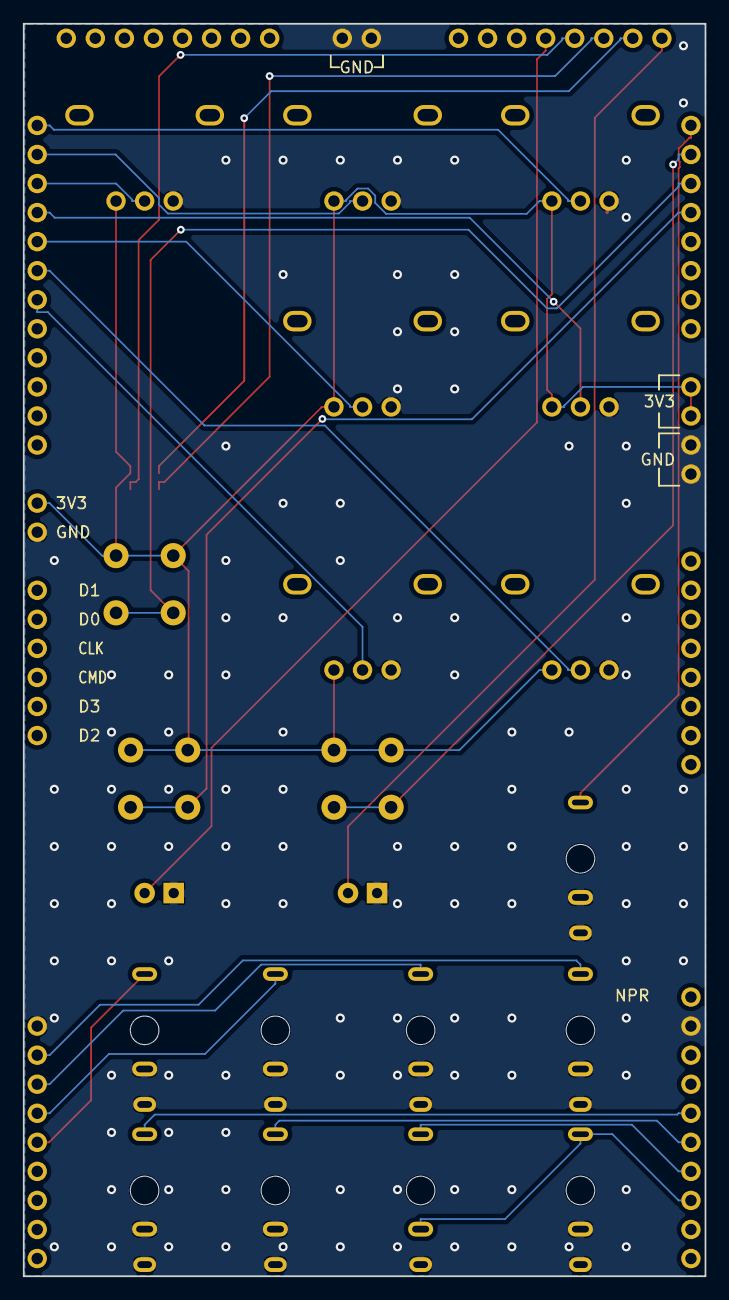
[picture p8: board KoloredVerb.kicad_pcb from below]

Board: 2 copper layers, 59.6 x 109.5 mm, 51 parts (11 on the bottom side), 26 nets.

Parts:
D1, D3: LED; LED_D3.0mm
D2: LED_RGBA; LED_Cree-PLCC4_3.2x2.8mm_CCW
H1: Header1; Empty
H2: Header2; Empty
H3, H4, H5, H6, H7, H8, H9: ROGAN 1PS; Empty
H10, H11, H12, H13, H14, H15, H16, H17, H18: KNURLED NUT; Empty
J1, J2, J3, J4, J5, J7, J8, J10, J12: IN; ThonkiconnJack
J6: POWER2; PinHeader_1x04_P2.54mm_Vertical
J9: POWER1; PinHeader_1x02_P2.54mm_Vertical
J11: GND; PinHeader_1x02_P2.54mm_Vertical
RV1, RV2, RV3, RV4, RV5, RV6, RV7: 100k; AlphaPot9ShaftD
SW1, SW2, SW3: SW_Push_Dual; SW_SPST_CKD6R
ZZ1: PX; PinHeader_1x12_P2.54mm_Vertical
ZZ2: CIX; PinHeader_1x09_P2.54mm_Vertical
ZZ3, ZZ7: BX; PinHeader_1x08_P2.54mm_Vertical
ZZ4, ZZ12: LX; PinHeader_1x08_P2.54mm_Vertical
ZZ5: ANALOG; PinHeader_1x10_P2.54mm_Vertical
ZZ10: SD; PinHeader_1x06_P2.54mm_Vertical

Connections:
+3V3: D2.4, J6.1, J6.2, J9.1, RV1.3, RV2.3, RV3.3, RV4.3, RV5.3, RV6.3, RV7.3, SW1.1, SW2.1, SW3.1
AI1: J7.T, J8.TN, ZZ5.8
AI2: J8.T, ZZ5.7
AO1: J10.T, ZZ5.6
AO2: J12.T, ZZ5.5
B1: J1.T, ZZ3.1
B2: SW1.2, ZZ3.2
B3: SW2.2, ZZ3.3
B4: SW3.2, ZZ3.4
CI1: J2.T, ZZ2.2
CI2: J3.T, ZZ2.3
CI3: J4.T, ZZ2.4
CI4: J5.T, ZZ2.5
GND: D1.1, D3.1, J1.S, J1.TN, J2.S, J2.TN, J3.S, J3.TN, J4.S, J4.TN, J5.S, J5.TN, J6.3, J6.4, J7.S, J7.TN, J8.S, J9.2, J10.S, J10.TN, J11.1, J11.2, J12.S, J12.TN, RV1.1, RV2.1, RV3.1, RV4.1, RV5.1, RV6.1, RV7.1, ZZ2.1, ZZ5.2
L1: D1.2, ZZ4.1
L2: D2.1, ZZ4.2
L3: D2.2, ZZ4.3
L4: D2.3, ZZ4.4
L5: D3.2, ZZ4.5
P1: RV1.2, ZZ1.1
P2: RV2.2, ZZ1.2
P3: RV3.2, ZZ1.3
P4: RV4.2, ZZ1.4
P5: RV5.2, ZZ1.5
P6: RV6.2, ZZ1.6
P7: RV7.2, ZZ1.7

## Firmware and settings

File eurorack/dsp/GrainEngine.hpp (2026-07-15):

#pragma once

#include <cmath>

namespace dsp
{

inline float rand01 (int & state)
{
	state = state * 1664525 + 1013904223;
	unsigned int x = static_cast <unsigned int> (state >> 1);
	return float (x & 0x7FFFFFFFu) / float (0x7FFFFFFFu);
}

inline void  GrainEngine::process (float in_l, float in_r, float & out_l, float & out_r)
{
	float wet_l = in_l;
	float wet_r = in_r;

	// Envelope follower to tie grain output to the reverb tail timing
	float in_abs = std::fabs (wet_l) + std::fabs (wet_r);
	if (in_abs > _env)
	{
		_env += _env_attack * (in_abs - _env);
	}
	else
	{
		_env += _env_release * (in_abs - _env);
	}

	if (_buf_size <= 2)
	{
		out_l = wet_l;
		out_r = wet_r;
		return;
	}

	// Use a looping delay line of length _loop_len (Faust: delayLength)
	int loop_len_i = _loop_len;
	if (loop_len_i < 2) loop_len_i = 2;
	if (loop_len_i > _buf_size) loop_len_i = _buf_size;

	if (_filled_len > loop_len_i) _filled_len = loop_len_i;

	// Write current input sample into the loop
	int write_pos = _write_pos;
	if (write_pos < 0) write_pos = 0;
	if (write_pos >= loop_len_i) write_pos %= loop_len_i;
	_buf_l [write_pos] = wet_l;
	_buf_r [write_pos] = wet_r;

	++_write_pos;
	if (_write_pos >= loop_len_i) _write_pos = 0;
	if (_filled_len < loop_len_i) ++_filled_len;

	int active_len_i = loop_len_i;
	if (_filled_len < active_len_i) active_len_i = _filled_len;
	if (active_len_i < 2)
	{
		out_l = wet_l;
		out_r = wet_r;
		return;
	}
	float loop_len_f = float (active_len_i);

	if (_grain_count <= 0 || _amount <= 0.f)
	{
		out_l = wet_l;
		out_r = wet_r;
		return;
	}

	float grain_len = _grain_size_s * _sample_freq;
	if (grain_len < 2.f) grain_len = 2.f;

	// Shorter base offsets reduce perceived latency and keep grains related to the current tail
	float base_offset_a = 0.10f * loop_len_f;
	float base_offset_b = 0.06f * loop_len_f;
	float jitter_scale  = _spread * loop_len_f * 0.10f;

	float step_a = _pitch_a;
	float step_b = _pitch_b;
	if (std::fabs (step_a) < 0.01f) step_a = (step_a < 0.f) ? -0.01f : 0.01f;
	if (std::fabs (step_b) < 0.01f) step_b = (step_b < 0.f) ? -0.01f : 0.01f;

	_phase_a += step_a;
	while (_phase_a >= grain_len) _phase_a -= grain_len;
	while (_phase_a < 0.f)        _phase_a += grain_len;
	_phase_b += step_b;
	while (_phase_b >= grain_len) _phase_b -= grain_len;
	while (_phase_b < 0.f)        _phase_b += grain_len;

	const float two_pi = 6.28318530717958647692f;
	float norm = 1.f;
	if (_grain_count > 0)
	{
		norm = 1.f / std::sqrt (float (_grain_count));
	}

	auto window = [&] (float ph) -> float
	{
		if (ph < 0.f) ph = 0.f;
		if (ph > 1.f) ph = 1.f;
		if (_window_type == 0)
		{
			return std::sin (ph * 3.14159265358979323846f);
		}
		if (_window_type == 1)
		{
			return 0.54f - 0.46f * std::cos (two_pi * ph);
		}
		return 1.f
			- 1.93f * std::cos (two_pi * ph)
			+ 1.29f * std::cos (2.f * two_pi * ph)
			- 0.388f * std::cos (3.f * two_pi * ph)
			+ 0.028f * std::cos (4.f * two_pi * ph);
	};

	auto wrap_loop = [&] (float pos) -> float
	{
		while (pos >= loop_len_f) pos -= loop_len_f;
		while (pos < 0.f)         pos += loop_len_f;
		return pos;
	};

	auto idx_wrap = [&] (int idx) -> int
	{
		while (idx < 0) idx += active_len_i;
		while (idx >= active_len_i) idx -= active_len_i;
		return idx;
	};

	auto interp_hermite = [&] (const std::vector <float> & buf, float pos) -> float
	{
		pos = wrap_loop (pos);
		int idx1 = int (pos);
		float x = pos - float (idx1);
		int idx0 = idx_wrap (idx1 - 1);
		int idx2 = idx_wrap (idx1 + 1);
		int idx3 = idx_wrap (idx1 + 2);
		idx1 = idx_wrap (idx1);

		float y0 = buf [idx0];
		float y1 = buf [idx1];
		float y2 = buf [idx2];
		float y3 = buf [idx3];

		float c0 = y1;
		float c1 = 0.5f * (y2 - y0);
		float c2 = y0 - 2.5f * y1 + 2.f * y2 - 0.5f * y3;
		float c3 = 0.5f * (y3 - y0) + 1.5f * (y1 - y2);
		return ((c3 * x + c2) * x + c1) * x + c0;
	};

	float acc_l = 0.f;
	float acc_r = 0.f;

	for (int i = 0 ; i < _grain_count ; ++i)
	{
		Grain & g = _grains [i];

		float ca = _phase_a + g.offset_a;
		while (ca >= grain_len) ca -= grain_len;
		while (ca < 0.f)        ca += grain_len;
		float cb = _phase_b + g.offset_b;
		while (cb >= grain_len) cb -= grain_len;
		while (cb < 0.f)        cb += grain_len;

		bool wrap_a = (step_a >= 0.f) ? (ca < g.prev_phase_a) : (ca > g.prev_phase_a);
		bool wrap_b = (step_b >= 0.f) ? (cb < g.prev_phase_b) : (cb > g.prev_phase_b);
		g.prev_phase_a = ca;
		g.prev_phase_b = cb;

		if (wrap_a)
		{
			// Choose start positions relative to the write head (coherent texture)
			// Base offset: read from the recent past inside the loop.
			float jitter = (rand01 (_rand_state) * 2.f - 1.f) * jitter_scale;
			g.start_a = wrap_loop (float (write_pos) - base_offset_a + jitter);
		}
		if (wrap_b)
		{
			float jitter = (rand01 (_rand_state) * 2.f - 1.f) * jitter_scale;
			g.start_b = wrap_loop (float (write_pos) - base_offset_b + jitter);
		}

		// Initialize immediately when enabling the effect (prevents delayed onset)
		if (g.start_a < 0.f)
		{
			g.start_a = wrap_loop (float (write_pos) - base_offset_a);
			g.prev_phase_a = ca;
		}
		if (g.start_b < 0.f)
		{
			g.start_b = wrap_loop (float (write_pos) - base_offset_b);
			g.prev_phase_b = cb;
		}

		float pos_a = wrap_loop (g.start_a + ca);
		float pos_b = wrap_loop (g.start_b + cb);

		float la = interp_hermite (_buf_l, pos_a);
		float ra = interp_hermite (_buf_r, pos_a);
		float lb = interp_hermite (_buf_l, pos_b);
		float rb = interp_hermite (_buf_r, pos_b);

		float wa = window (ca / grain_len);
		float wb = window (cb / grain_len);

		float gl = (la * wa + lb * wb) * 0.5f;
		float gr = (ra * wa + rb * wb) * 0.5f;

		acc_l += gl * g.pan_l * norm;
		acc_r += gr * g.pan_r * norm;
	}

	// Additive layer: keep reverb tail present while adding grain cloud on top.
	// This avoids the "FX up -> reverb disappears" perception.
	float x = _amount;
	if (x < 0.f) x = 0.f;
	if (x > 1.f) x = 1.f;

	float grain_gain = 0.f;
	if (x > 0.03f)
	{
		float t = (x - 0.03f) / 0.97f;
		if (t < 0.f) t = 0.f;
		if (t > 1.f) t = 1.f;
		// Stronger gain curve so granulation is clearly audible
		float shaped = std::pow (t, 0.55f);
		grain_gain = 0.4f + 1.6f * shaped;
	}

	// Shape grain output by tail envelope (release is dynamically tied to reverb decay).
	// Use sqrt for a gentler fade that keeps grains audible longer during the tail.
	float env_shape = std::sqrt (_env * 4.f);
	if (env_shape > 1.f) env_shape = 1.f;
	grain_gain *= env_shape;

	out_l = wet_l + acc_l * grain_gain;
	out_r = wet_r + acc_r * grain_gain;
}

} // namespace dsp

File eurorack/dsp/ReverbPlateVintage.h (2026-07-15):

/*****************************************************************************

     ReverbPlateVintage.h
     Plate (vintage): steel-plate voicing, HF decay clamped off the decay knob.

*Tab=3***********************************************************************/

#pragma once

#include "ReverbModel.h"
#include "erb/SdramPtr.h"

#include <array>
#include <cmath>

namespace dsp
{

class ReverbPlateVintage : public ReverbModel
{
public:
   explicit       ReverbPlateVintage (float sample_freq);

   // measured plates run ~1 s (damper closed) to ~5 s (open) at 500 Hz
   void           set_decay (float d) override
   {
      _gain = 0.820f + clamp01 (d) * 0.141f;
      update_damp ();
   }

   // macro = damper travel: the physical plate damper trades decay for a
   // response that flattens out with frequency as it closes in
   void           set_macro (float fx) override { _tone = clamp01 (fx); update_damp (); }

   void           set_low_pass_freq (float) override {}   // voicing is fixed: it is the instrument

   void           reset () override
   {
      auto & B = *_buf;
      B.d0.fill (0.f); B.d1.fill (0.f); B.d2.fill (0.f); B.d3.fill (0.f);
      for (auto & a : B.di) a.fill (0.f);
      _wp = 0;
      _sh0 = _sh1 = _sh2 = _sh3 = 0.f;
      _in_lp = 0.f; _o_lp_l = _o_lp_r = _o_hp_l = _o_hp_r = 0.f;
      _lfo = 0.f;
   }

   StereoFrame    process (StereoFrame in) override
   {
      auto & B = *_buf;

      // the exciter drives a steel sheet, not a room: nothing above ~3 kHz gets
      // into the plate in the first place
      _in_lp += _in_c * (0.5f * (in.left + in.right) - _in_lp);
      float x = diffuse (_in_lp);

      float md = 1.6f * std::sin (_lfo);
      _lfo += _lfo_inc; if (_lfo >= 6.2831853f) _lfo -= 6.2831853f;

      float a = read (B.d0, float (L0) + md);
      float b = read (B.d1, float (L1) - md);
      float c = read (B.d2, float (L2) + md * 0.7f);
      float d = read (B.d3, float (L3) - md * 0.7f);

      a = shelf (_sh0, a); b = shelf (_sh1, b);
      c = shelf (_sh2, c); d = shelf (_sh3, d);

      float s0 = 0.5f * ( a + b + c + d);
      float s1 = 0.5f * ( a - b + c - d);
      float s2 = 0.5f * ( a + b - c - d);
      float s3 = 0.5f * ( a - b - c + d);

      B.d0 [_wp & DMASK] = soft (x + _gain * s0);
      B.d1 [_wp & DMASK] = soft (x + _gain * s1);
      B.d2 [_wp & DMASK] = soft (x + _gain * s2);
      B.d3 [_wp & DMASK] = soft (x + _gain * s3);
      ++_wp;

      // pickups sat at unequal distances from the exciter, so L/R never matched
      float yl = 0.6f * a + 0.4f * c;
      float yr = 0.6f * d + 0.4f * b;
      return { band (_o_lp_l, _o_hp_l, yl) * NORM, band (_o_lp_r, _o_hp_r, yr) * NORM };
   }

private:
   static constexpr unsigned D = 2048, DMASK = 2047;
   static constexpr unsigned DI = 512, DIMASK = 511;
   // a 2 m plate crosses in ~20 ms at 500 Hz
   static constexpr int L0 = 953, L1 = 1193, L2 = 1511, L3 = 1889;
   // the late tail is set by the slowest line, not the average
   static constexpr float L_REF = float (L3);
   static constexpr float NORM = 1.35f;

   // a real plate holds ~1.3 modes/Hz against the ~3/Hz that reads as
   // colourless, so it is coloured by construction: diffuse less than the
   // bright plate does, or the voice stops being a plate
   static constexpr int DL [3] = { 113, 191, 269 };

   struct Buffers
   {
      std::array<float,D>                d0{}, d1{}, d2{}, d3{};
      std::array<std::array<float,DI>,3> di{};
   };

   static float   soft (float x)
   {
      if (x < -1.5f) return -1.f;
      if (x >  1.5f) return  1.f;
      return x - x * x * x * (1.f / 6.75f);
   }

   // Measured plates hold HF decay near 1-1.5 s at every damper setting while
   // the low end runs several times longer, so HF loss has to cancel the decay
   // gain instead of adding to it. Short settings flatten out because the
   // required relative gain clips at 1 -- which is what the plate does too.
   void           update_damp ()
   {
      float t60_hf = 1.05f + _tone * 0.55f;
      float g_hf = std::pow (10.f, -3.f * L_REF / (t60_hf * _sr));
      _hf_rel = g_hf / _gain;
      if (_hf_rel > 1.f) _hf_rel = 1.f;
      if (_hf_rel < 0.05f) _hf_rel = 0.05f;
   }

   float          shelf (float & s, float x) const
   {
      s += _sh_c * (x - s);                     // DC gain 1, HF gain _hf_rel
      return _hf_rel * x + (1.f - _hf_rel) * s;
   }

   // plate response peaks near 300 Hz and is ~18 dB down by 10 kHz
   float          band (float & lp, float & hp, float x) const
   {
      lp += _o_lp_c * (x - lp);
      hp += _o_hp_c * (lp - hp);
      return lp - hp;
   }

   float          diffuse (float x)
   {
      auto & B = *_buf;
      for (int i = 0 ; i < 3 ; ++i)
      {
         auto & buf = B.di[i];
         float dv = buf [(_wp - unsigned (DL[i])) & DIMASK];
         float y = -0.62f * x + dv;
         buf [_wp & DIMASK] = x + 0.62f * y;
         x = y;
      }
      return x;
   }

   float          read (const std::array<float,D> & b, float delay) const
   {
      float rp = float (_wp & DMASK) - delay;
      while (rp < 0.f) rp += float (D);
      int i1 = int (rp) & int (DMASK); float f = rp - std::floor (rp);
      int i0 = (i1 - 1) & int (DMASK), i2 = (i1 + 1) & int (DMASK), i3 = (i1 + 2) & int (DMASK);
      float y0 = b[i0], y1 = b[i1], y2 = b[i2], y3 = b[i3];
      float c1 = 0.5f*(y2-y0), c2 = y0 - 2.5f*y1 + 2.f*y2 - 0.5f*y3, c3 = 0.5f*(y3-y0)+1.5f*(y1-y2);
      return ((c3*f + c2)*f + c1)*f + y1;
   }

   static float   one_pole (float fc, float sr)
   {
      float c = 1.f - std::exp (-6.2831853f * fc / sr);
      if (c < 0.f) c = 0.f;
      if (c > 1.f) c = 1.f;
      return c;
   }

   float          _sr;
   erb::SdramPtr<Buffers> _buf;
   float          _gain = 0.85f, _tone = 0.5f, _hf_rel = 0.5f;
   float          _in_c = 0.2f, _sh_c = 0.3f, _o_lp_c = 0.2f, _o_hp_c = 0.02f;
   float          _sh0 = 0.f, _sh1 = 0.f, _sh2 = 0.f, _sh3 = 0.f;
   float          _in_lp = 0.f;
   float          _o_lp_l = 0.f, _o_lp_r = 0.f, _o_hp_l = 0.f, _o_hp_r = 0.f;
   float          _lfo = 0.f, _lfo_inc = 0.f;
   unsigned       _wp = 0;
};

inline ReverbPlateVintage::ReverbPlateVintage (float sample_freq)
:  _sr (sample_freq)
,  _buf (erb::make_sdram<Buffers> ())
{
   _in_c   = one_pole (2800.f, _sr);
   _sh_c   = one_pole (1000.f, _sr);   // low corner: the shelf must reach its
                                       // asymptote by 8 kHz or the clamp leaks
   _o_lp_c = one_pole (1800.f, _sr);
   _o_hp_c = one_pole ( 130.f, _sr);
   _lfo_inc = 6.2831853f * 1.0f / _sr;   // Dattorro's tank runs ~1 Hz
   update_damp ();
   reset ();
}

}  // namespace dsp

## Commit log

2026-07-15 Add module DSP wrapper, UI glue and panel definition
2026-07-15 Add hardware artifacts for fabrication
    [GlacialReverb.bom.csv, GlacialReverb.kicad_pcb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]
2026-07-15 Block DC in the Shimmer grain feedback
    Shimmer latched to a DC rail at high FX/DECAY with no input at all. Abyss runs the identical loop and was kept off it only by this blocker.
2026-07-15 Block DC on the wet feed
    Eurorack inputs are DC-coupled and the dampers have unity DC gain, so an input offset was amplified ~10x until the wet railed. The dry stays a passthrough.
2026-07-15 Give the wet limiter a threshold and trim the two hot models
    Plate peaked 2.52 and Hall 1.62 into a 1.5 knee, hard-clipping every transient. The limiter was a static cubic with no threshold, so it coloured every model at every level; it is now transparent belo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
2026-07-15 Crossfade rooms and effects instead of muting the tail
    The ramp only faded in the incoming voice, which had just been reset and was silent, so every switch deleted the tail for ~200 ms. Render both across a 150 ms ramp and clear the outgoing voice once it is silent.
2026-07-15 Add a chamber room built on early reflections
    A Moorer tap bank alone runs ~240 echoes/s against the ~1000/s that reads as diffuse, so the tank is excited by the taps rather than the input and the density comes out of the recirculation.
2026-07-15 Replace the modal plate and spring with voices that can work
    A credible plate needs ~25k modes; 128 already costs ~55 Mflop/s, so the modal banks were two orders of magnitude short and quantised pitch to their mode grid. The vintage plate holds HF decay near a second whatever the decay knob does, as a steel plate does; the long tank spreads its three delays while keeping the chirp cutoffs together, and scatters at the mid-point coupling ring.
    [ReverbPlateVintage.h]
2026-07-15 Add the three headers missing from the BOM
    ZZ7, ZZ12 (8-pos) and ZZ10 (6-pos) are on the board but were never listed, so an order from this BOM came up short. Verified against the PCB: every footprint with pads now has a line, and every quantity matches its reference count.
    [GlacialReverb.bom.csv]
2026-07-15 Add JLCPCB ordering files for the kivu12
    The framework's fab set mixes 97 SMD parts with 35 hand-solder rows and 4 tooling rows, split by '#' comments that JLCPCB's uploader reads as data. These are the same rows minus the ones it cannot pl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
    [kivu12-jlcpcb-bom.csv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]
2026-07-16 Add EUPL-1.2 licence and third-party provenance
    EUPL-1.2 for the original work; the header records what it does not cover: ReverbSc stays MIT, and the boards stay CC BY-SA 4.0 by derivation from eurorack-blocks. THIRD-PARTY.md traces each dependen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
2026-07-16 Add CI and release workflows
    CI runs the DSP smoke test and KiCad DRC on every push, both from committed files only and both proven locally. Release packages the hardware bundle (gerbers, BOM, kivu12 fab, board PDFs) on a v* tag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
2026-07-16 Wait for the VCV jobs before publishing the release
    The publish job only needed [hardware], so it ran before the VCV artifacts existed and attached hardware.zip alone even when a plugin built fine. It now needs [hardware, vcv] with always() + a hardwa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
2026-07-17 ci: build VCV plugin for Intel, ARM, and Linux
2026-08-22 Rename to Koloured-Verb and split the hardware into three boards
    [GlacialReverb.panel-B_Cu.gbl, GlacialReverb.panel-B_Cu.gbr, GlacialReverb.panel-B_Mask.gbr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]
2026-08-22 Add the core board, a kivu12 trimmed to what this module uses
    [KoloredVerb.core-B_Cu.gbr, KoloredVerb.core-B_Mask.gbr, KoloredVerb.core-B_Paste.gbr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]
2026-08-22 Cut the control board solder mask expansion to 0.0762 mm
    [KoloredVerb-B_Cu.gbr, KoloredVerb-B_Mask.gbr, KoloredVerb-B_Paste.gbr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]
2026-08-22 Ignore unresolvable footprint library on the panel
2026-08-22 Ignore unresolvable library references in core board ERC
2026-08-22 Keep fabrication files byte-exact through git
    [KoloredVerb-B_Cu.gbr, KoloredVerb-B_Mask.gbr, KoloredVerb-B_Paste.gbr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]
2026-08-22 Drop the core board schematic's leftovers from the trim
    [KoloredVerb.core-B_Cu.gbr, KoloredVerb.core-B_Mask.gbr, KoloredVerb.core-B_Paste.gbr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]
2026-08-22 Remove the eurorack-blocks logo from the core board
    [KoloredVerb.core-B_Cu.gbr, KoloredVerb.core-B_Mask.gbr, KoloredVerb.core-B_Paste.gbr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]
2026-08-27 Replace the ROOM trigger jack with a DECAY CV input
    [KoloredVerb.panel-B_Cu.gbr, KoloredVerb.panel-B_Mask.gbr, KoloredVerb.panel-B_Silkscreen.gbr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]
2026-08-27 Route the DECAY CV jack to CI4 on the control board
    [KoloredVerb-B_Cu.gbr, KoloredVerb-B_Mask.gbr, KoloredVerb-B_Paste.gbr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]
2026-08-27 Verify parts against datasheets, add MPNs, drop stale silkscreen
    [KoloredVerb.bom.csv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]
